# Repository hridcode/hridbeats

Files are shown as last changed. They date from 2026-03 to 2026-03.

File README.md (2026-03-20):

# hridBeats
hridBeats is an open-source sample chopper, synth, and MIDI controller based off the Raspberry Pi Pico. 

# Features

- 12 touchpads
- 8 potentiometers
- rotary encoder with a pushbutton
- joystick for mouse control
- TFT LCD 2.0" ST7789 display
- PCM5102A I2S DAC board for audio output
- SD card slot for loading songs/samples
- MIDI through USB
- Mini synth engine

# Pictures

|Schematic|PCB|Case|
|---|---|---|
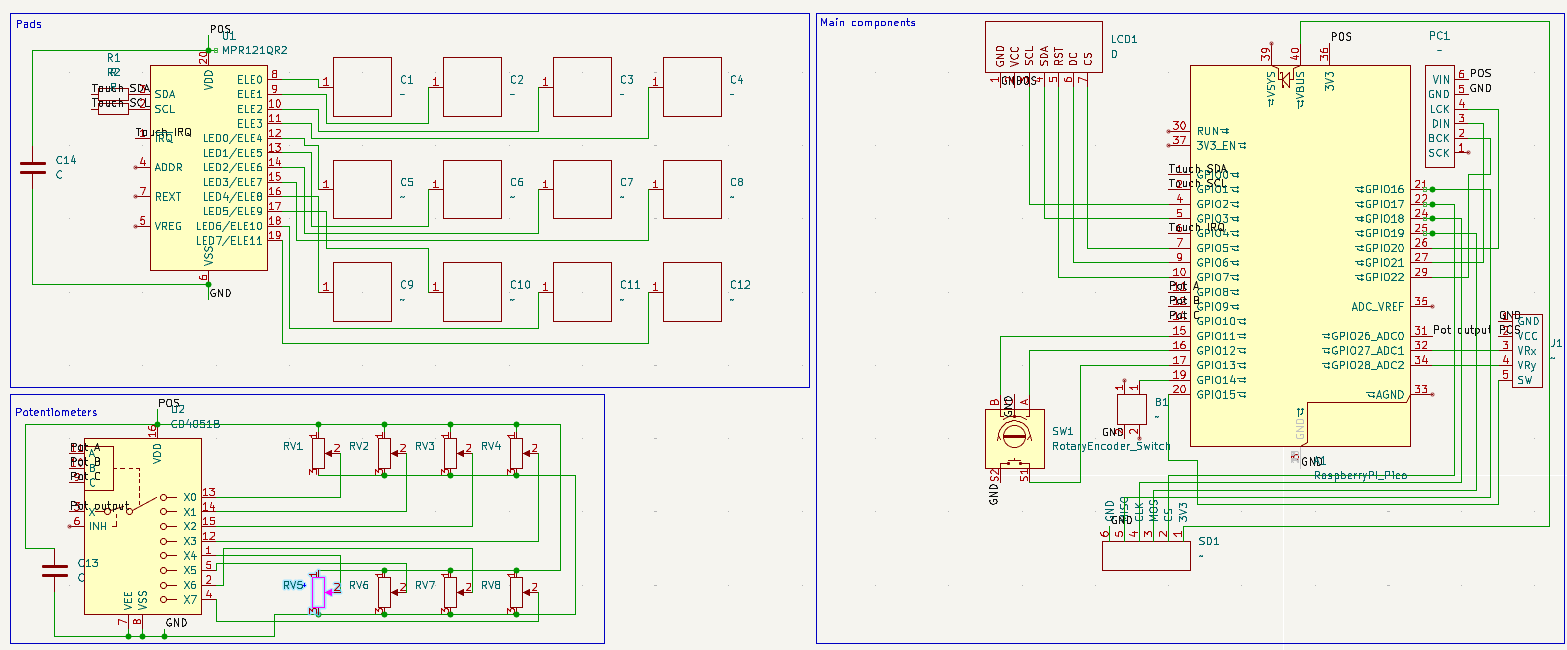
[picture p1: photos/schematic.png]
Image of schematic
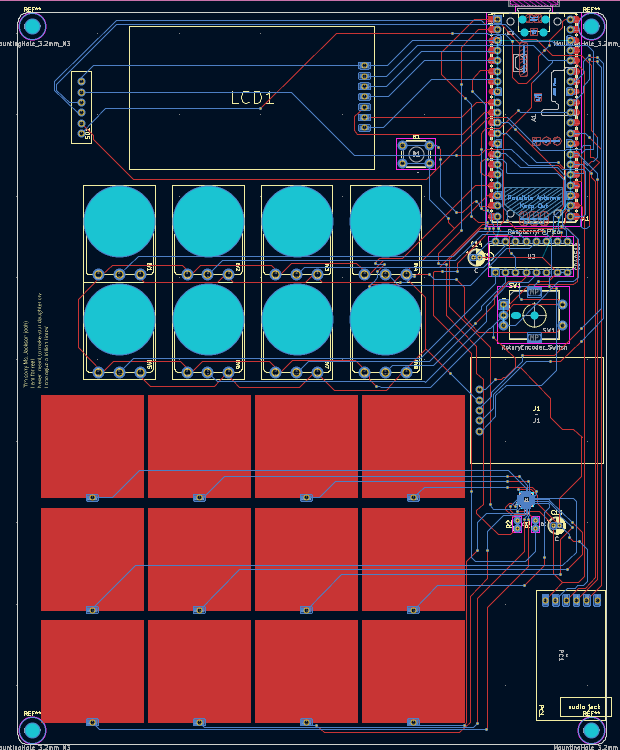
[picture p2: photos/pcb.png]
Image of PCB
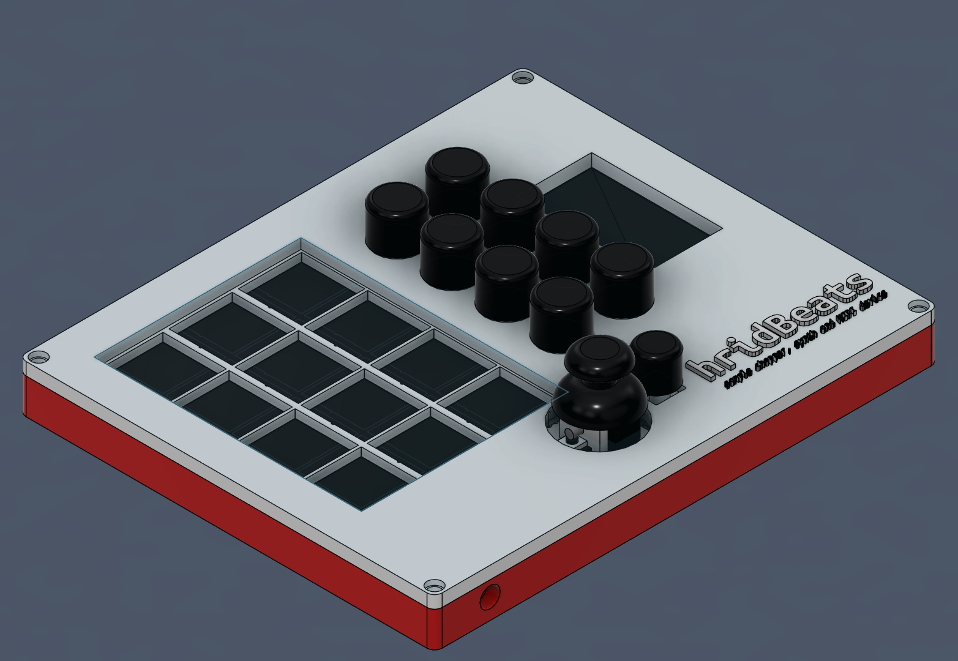
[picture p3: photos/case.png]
Image of case
||||

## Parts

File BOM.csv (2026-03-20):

Item | Count | Price | Link
MPR121QR2 | 1 | 1 | https://www.aliexpress.us/item/3256806758406295.html?curPageLogUid=pTX3BiAzX3DO
PCM5102A I2S DAC board | 1 | 2.28 | https://www.aliexpress.us/item/3256808911242738.html?curPageLogUid=evOArS7vqeJX
2.0" TFT LCD ST7789 display | 1 | 3.76 | https://www.aliexpress.us/item/3256808604687621.html?curPageLogUid=fdDO3YdVQrhY
WH148 potentiometer | 10 | 4.02 | https://www.aliexpress.us/item/3256808118980669.html?curPageLogUid=byGJ2gZeQC04
EC11 rotary encoder (w/ push button) | 1 | 0.65 | https://www.aliexpress.us/item/2261799870168498.html?curPageLogUid=hjV5hj8fpuzV
KY-023 joystick module | 1 | 1.25 | https://www.aliexpress.us/item/3256807353588090.html?curPageLogUid=3KMLlz3LYJ8L
Raspberry Pi Pico | 1 | 3.95 | https://www.pishop.us/product/raspberry-pi-pico/?src=raspberrypi
M3 heatset inserts 3x5x4 | 8 | 0.32 | https://www.aliexpress.us/item/3256806651793931.html?curPageLogUid=qsMqfJvH4nXo
M3x8 screws | 8 | 0.32 | https://www.aliexpress.us/item/3256804883804669.html?curPageLogUid=Ex37TlD5EHOc
3D printed parts (12 pads, 9 knobs, top & bottom case) | 23 | - | -
PCB | 1 | 2.76 | https://cart.jlcpcb.com/quote?stencilLayer=2&stencilWidth=144&stencilLength=169&stencilCounts=5&plateType=1
Total | - | 20.31

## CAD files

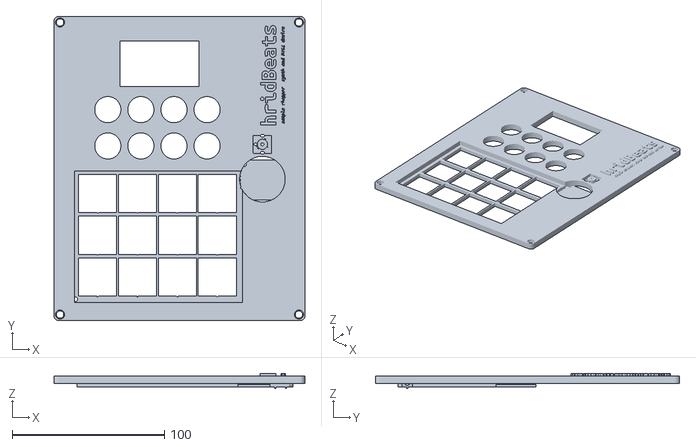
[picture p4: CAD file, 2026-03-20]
production/cad/TopCase.stl
165.0 x 200.0 x 9.77

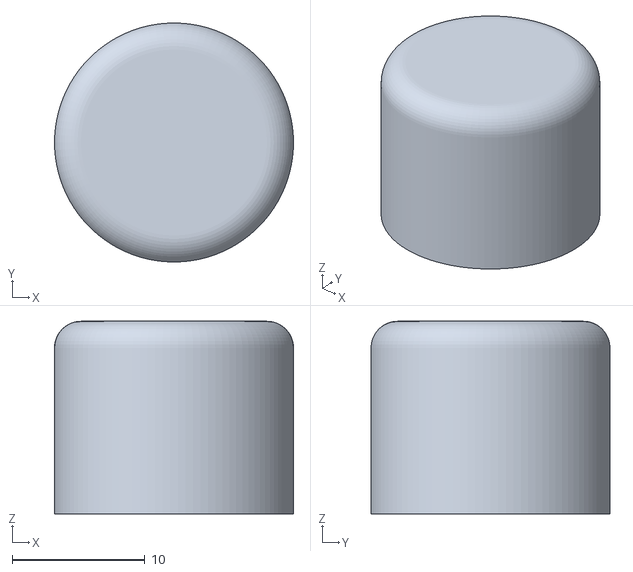
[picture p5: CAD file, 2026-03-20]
production/cad/Knob.stl
18.0 x 18.0 x 14.5

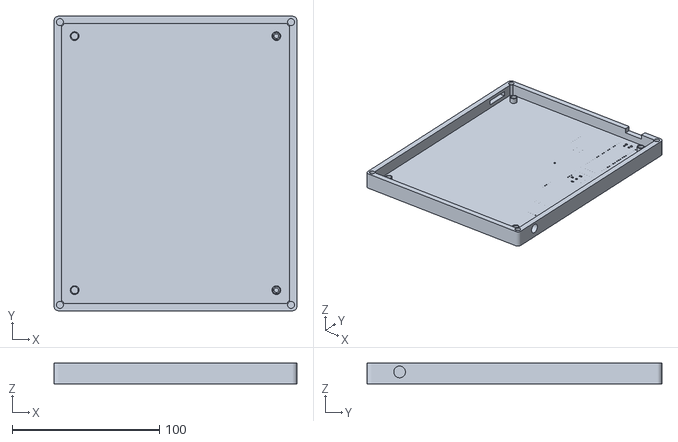
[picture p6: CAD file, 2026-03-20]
production/cad/BottomCase.stl
165.0 x 200.0 x 14.0

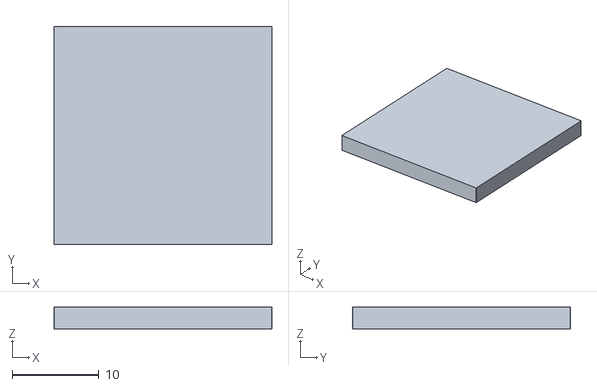
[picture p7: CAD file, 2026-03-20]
production/cad/Pad.stl
25.1 x 25.1 x 2.50

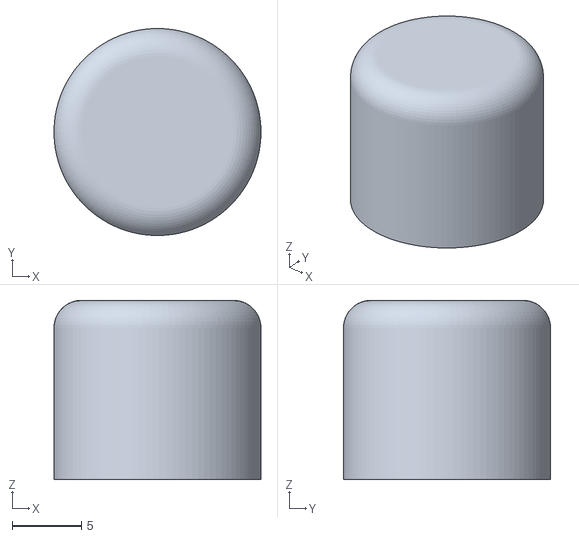
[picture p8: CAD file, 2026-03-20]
production/cad/Knob_RotaryEncoder.stl
15.0 x 15.0 x 13.0

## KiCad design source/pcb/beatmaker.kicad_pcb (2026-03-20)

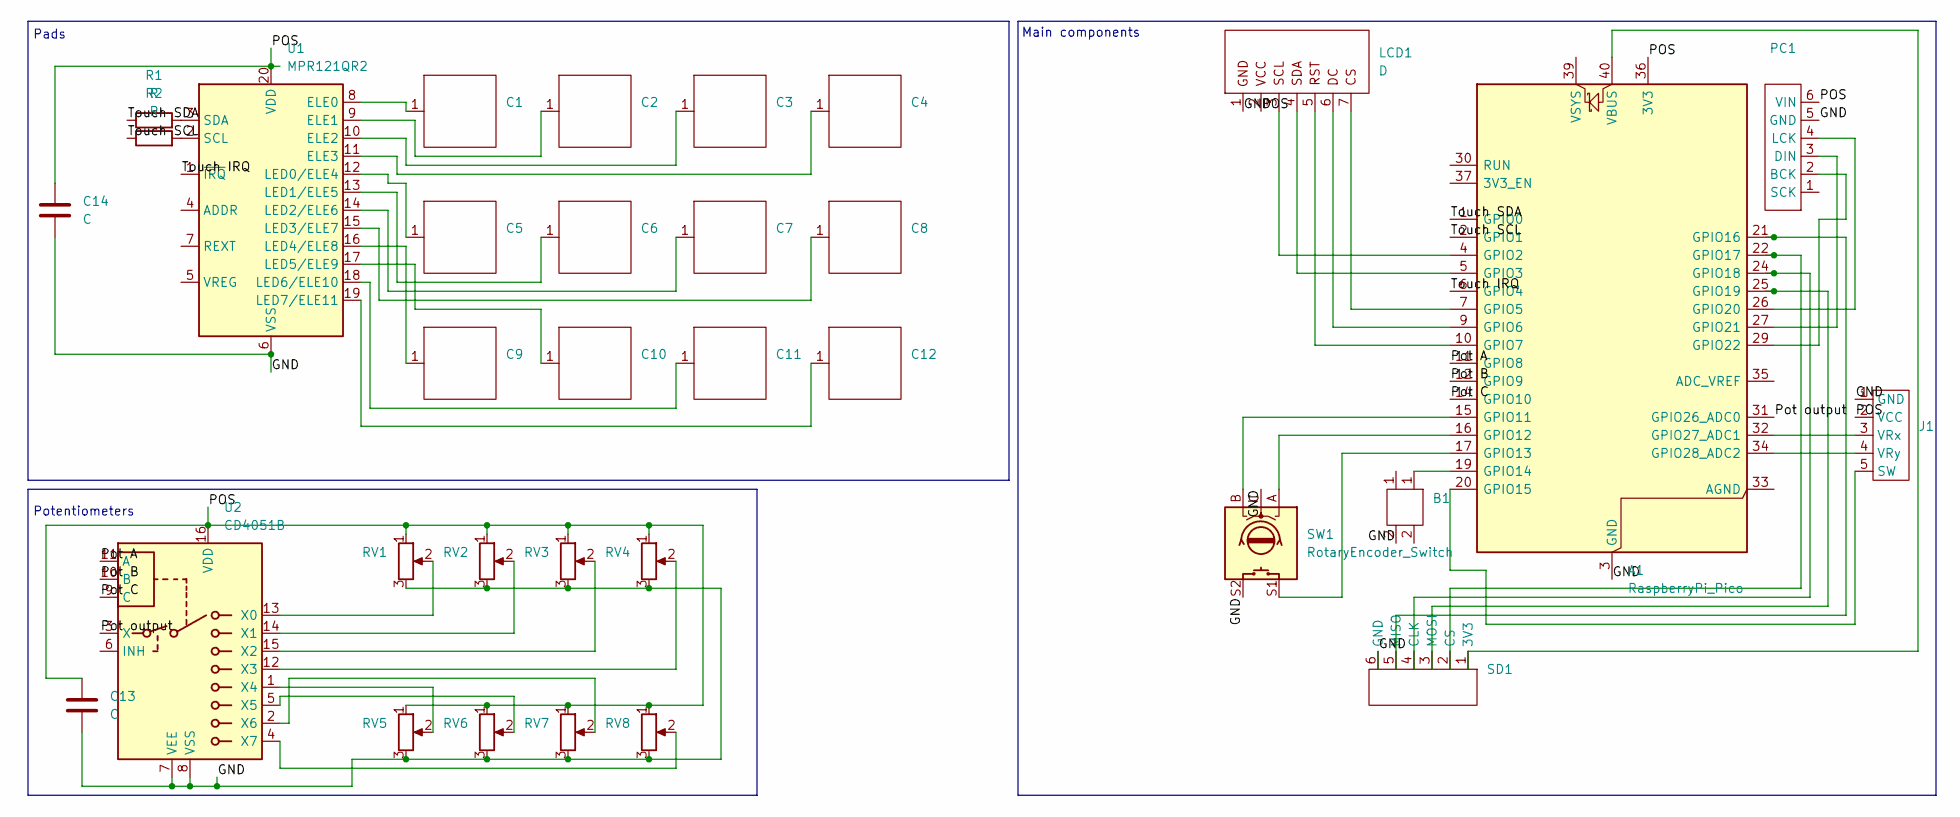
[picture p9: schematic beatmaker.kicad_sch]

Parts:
A1: RaspberryPi_Pico; RaspberryPi_Pico_Common_Unspecified
B1: SW_PUSH_6mm
C1, C2, C3, C4, C5, C6, C7, C8, C9, C10, C11, C12: copper_pad_25mm
C13, C14: C; CP_Radial_D4.0mm_P1.50mm
J1: ky-023-joystick
LCD1: D; ST7789
PC1: PCM5201-Board
R1, R2: R; R_Axial_DIN0204_L3.6mm_D1.6mm_P1.90mm_Vertical
RV1, RV2, RV3, RV4, RV5, RV6, RV7, RV8: R_Potentiometer; potentiometer
SD1: sd_card_module
SW1: RotaryEncoder_Switch; RotaryEncoder_Alps_EC11E-Switch_Vertical_H20mm_MountingHoles
U1: MPR121QR2; UQFN-20_3x3mm_P0.4mm
U2: CD4051B; DIP-16_W7.62mm

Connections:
/GND: A1.3 (GND), A1.8 (GND), A1.13 (GND), A1.18 (GND), A1.23 (GND), A1.28 (GND), A1.38 (GND), B1.2, C13.2, C14.2, J1.1 (GND), LCD1.1, PC1.5 (GND), RV1.3, RV2.3, RV3.3, RV4.3, RV5.3, RV6.3, RV7.3, RV8.3, SD1.6 (GND), SW1.C, SW1.S2, U1.6 (VSS), U2.7 (VEE), U2.8 (VSS)
/POS: A1.36 (3V3), C13.1, C14.1, J1.2 (VCC), LCD1.2, PC1.6 (VIN), RV1.1, RV2.1, RV3.1, RV4.1, RV5.1, RV6.1, RV7.1, RV8.1, U1.20 (VDD), U2.16 (VDD)
/Pot A: A1.11 (GPIO8), U2.11 (A)
/Pot B: A1.12 (GPIO9), U2.10 (B)
/Pot C: A1.14 (GPIO10), U2.9 (C)
/Pot output: A1.31 (GPIO26_ADC0), U2.3 (X)
/Touch IRQ: A1.6 (GPIO4), U1.1 (~IRQ)
/Touch SCL: A1.2 (GPIO1), R2.1
/Touch SDA: A1.1 (GPIO0), R1.1
unnamed: A1.4 (GPIO2), LCD1.3
unnamed: A1.5 (GPIO3), LCD1.4
unnamed: A1.7 (GPIO5), LCD1.7
unnamed: A1.9 (GPIO6), LCD1.6
unnamed: A1.10 (GPIO7), LCD1.5
unnamed: A1.15 (GPIO11), SW1.B
unnamed: A1.16 (GPIO12), SW1.A
unnamed: A1.17 (GPIO13), SW1.S1
unnamed: A1.19 (GPIO14), B1.1
unnamed: A1.20 (GPIO15), J1.5 (SW)
unnamed: A1.21 (GPIO16), SD1.5 (MISO)
unnamed: A1.22 (GPIO17), SD1.2 (CS)
unnamed: A1.24 (GPIO18), SD1.4 (CLK)
unnamed: A1.25 (GPIO19), SD1.3 (MOSI)
unnamed: A1.26 (GPIO20), PC1.4 (LCK)
unnamed: A1.27 (GPIO21), PC1.3 (DIN)
unnamed: A1.29 (GPIO22), PC1.2 (BCK)
unnamed: A1.32 (GPIO27_ADC1), J1.3 (VRx)
unnamed: A1.34 (GPIO28_ADC2), J1.4 (VRy)
unnamed: A1.40 (VBUS), SD1.1 (3V3)
unnamed: C1.1, U1.8 (ELE0)
unnamed: C2.1, U1.9 (ELE1)
unnamed: C3.1, U1.10 (ELE2)
unnamed: C4.1, U1.11 (ELE3)
unnamed: C5.1, U1.12 (LED0/ELE4)
unnamed: C6.1, U1.13 (LED1/ELE5)
unnamed: C7.1, U1.14 (LED2/ELE6)
unnamed: C8.1, U1.15 (LED3/ELE7)
unnamed: C9.1, U1.16 (LED4/ELE8)
unnamed: C10.1, U1.17 (LED5/ELE9)
unnamed: C11.1, U1.18 (LED6/ELE10)
unnamed: C12.1, U1.19 (LED7/ELE11)
unnamed: R2.2, U1.2 (SCL)
unnamed: R1.2, U1.3 (SDA)
unnamed: RV1.2, U2.13 (X0)
unnamed: RV2.2, U2.14 (X1)
unnamed: RV3.2, U2.15 (X2)
unnamed: RV4.2, U2.12 (X3)
unnamed: RV5.2, U2.1 (X4)
unnamed: RV6.2, U2.5 (X5)
unnamed: RV7.2, U2.2 (X6)
unnamed: RV8.2, U2.4 (X7)

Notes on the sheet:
Pads
Potentiometers
Main components

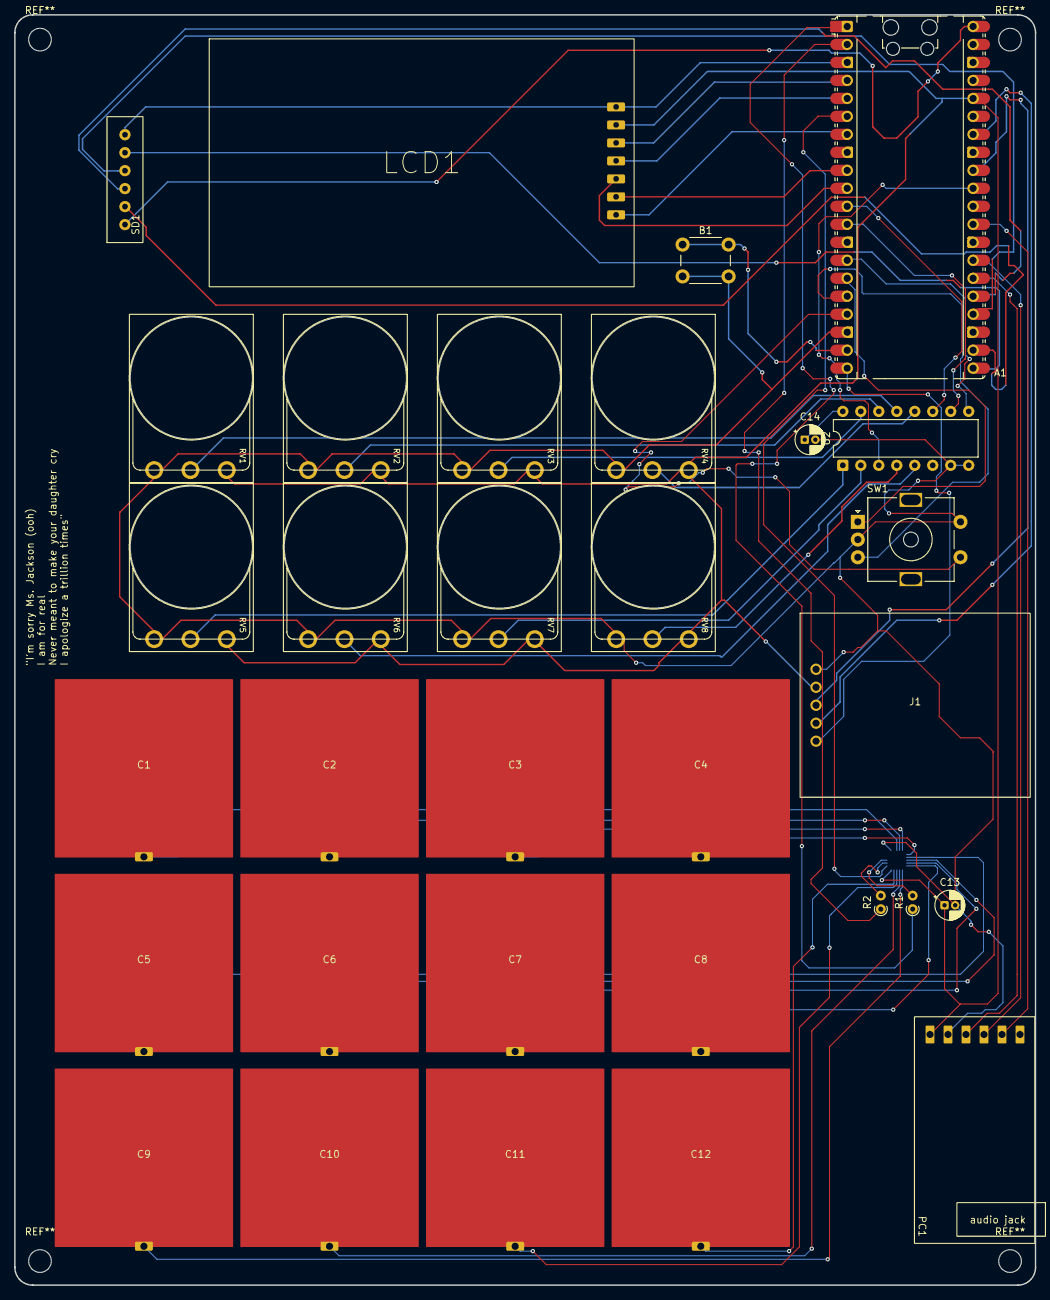
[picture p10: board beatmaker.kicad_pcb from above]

Board: 2 copper layers, 144.2 x 179.4 mm, 33 parts (1 on the bottom side), 51 nets.

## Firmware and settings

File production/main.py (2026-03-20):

from machine import Pin, PWM, SPI, ADC
from sdcard import SDCard
import spleen8, spleen16
import layout
import time, os
import framebuf
from st7789py import color565, WHITE, YELLOW

joystick_x, joystick_y = ADC(Pin(27)), ADC(Pin(28))
joystick_sw = Pin(15, pull=Pin.PULL_UP)

pot = ADC(Pin(26))
pot_left, pot_right = Pin(8, pull=Pin.PULL_UP), Pin(9, pull=Pin.PULL_UP)

rotary_l, rotary_r = Pin(11), Pin(12)
rotary_push = Pin(13, pull=Pin.PULL_UP)

int_button = Pin(14, pull=Pin.PULL_UP)

sd_spi = SPI(0, sck=Pin(18, Pin.OUT), mosi=Pin(19, Pin.OUT), miso=Pin(16))
sd_cs = Pin(17, Pin.OUT)

sd = SDCard(sd_spi, sd_cs)

vfs = os.VfsFat(sd) # type: ignore

os.mount(vfs, "/sd")
print("Filesystem check")
print(os.listdir("/sd"))

BG_COLOR = color565(75, 86, 130)
STATUS_BAR_GRAY = color565(80, 80, 80)
BUTTON_GRAY = color565(170, 170, 170)

screen = layout.Screen(BG_COLOR)

home_root = layout.Container(0, 0, 320, 240)
status = layout.StatusBar(0, 32, "Hello world!", STATUS_BAR_GRAY, WHITE)
home_root.add(status)

new_project_button = layout.Button(160, 100, 210, 50, "New Project", BUTTON_GRAY, WHITE, STATUS_BAR_GRAY)
open_project_button = layout.Button(160, 172, 210, 50, "Open Project", BUTTON_GRAY, WHITE, STATUS_BAR_GRAY)
home_root.add(new_project_button, open_project_button)

screen.set_root(home_root)

screen.render(fill=True, layout=True)

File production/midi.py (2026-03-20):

# MicroPython USB MIDI module
# MIT license; Copyright (c) 2023 Paul Hamshere, 2023-2024 Angus Gratton
from micropython import const, schedule
import struct

from .core import Interface, Buffer

_EP_IN_FLAG = const(1 << 7)

_INTERFACE_CLASS_AUDIO = const(0x01)
_INTERFACE_SUBCLASS_AUDIO_CONTROL = const(0x01)
_INTERFACE_SUBCLASS_AUDIO_MIDISTREAMING = const(0x03)

# Audio subclass extends the standard endpoint descriptor
# with two extra bytes
_STD_DESC_AUDIO_ENDPOINT_LEN = const(9)
_CLASS_DESC_ENDPOINT_LEN = const(5)

_STD_DESC_ENDPOINT_TYPE = const(0x5)

_JACK_TYPE_EMBEDDED = const(0x01)
_JACK_TYPE_EXTERNAL = const(0x02)

_JACK_IN_DESC_LEN = const(6)
_JACK_OUT_DESC_LEN = const(9)

# MIDI Status bytes. For Channel messages these are only the upper 4 bits, ORed with the channel number.
# As per https://www.midi.org/specifications-old/item/table-1-summary-of-midi-message
_MIDI_NOTE_OFF = const(0x80)
_MIDI_NOTE_ON = const(0x90)
_MIDI_POLY_KEYPRESS = const(0xA0)
_MIDI_CONTROL_CHANGE = const(0xB0)

# USB-MIDI CINs (Code Index Numbers), as per USB MIDI Table 4-1
_CIN_SYS_COMMON_2BYTE = const(0x2)
_CIN_SYS_COMMON_3BYTE = const(0x3)
_CIN_SYSEX_START = const(0x4)
_CIN_SYSEX_END_1BYTE = const(0x5)
_CIN_SYSEX_END_2BYTE = const(0x6)
_CIN_SYSEX_END_3BYTE = const(0x7)
_CIN_NOTE_OFF = const(0x8)
_CIN_NOTE_ON = const(0x9)
_CIN_POLY_KEYPRESS = const(0xA)
_CIN_CONTROL_CHANGE = const(0xB)
_CIN_PROGRAM_CHANGE = const(0xC)
_CIN_CHANNEL_PRESSURE = const(0xD)
_CIN_PITCH_BEND = const(0xE)
_CIN_SINGLE_BYTE = const(0xF)  # Not currently supported

# Jack IDs for a simple bidrectional MIDI device(!)
_EMB_IN_JACK_ID = const(1)
_EXT_IN_JACK_ID = const(2)
_EMB_OUT_JACK_ID = const(3)
_EXT_OUT_JACK_ID = const(4)

# Data flows, as modelled by USB-MIDI and this hypothetical interface, are as follows:
# Device RX = USB OUT EP => _EMB_IN_JACK => _EMB_OUT_JACK
# Device TX = _EXT_IN_JACK => _EMB_OUT_JACK => USB IN EP


class MIDIInterface(Interface):
    # Base class to implement a USB MIDI device in Python.
    #
    # To be compliant this also registers a dummy USB Audio interface, but that
    # interface isn't otherwise used.

    def __init__(self, rxlen=16, txlen=16):
        # Arguments are size of transmit and receive buffers in bytes.

        super().__init__()
        self.ep_out = None  # Set during enumeration. RX direction (host to device)
        self.ep_in = None  # TX direction (device to host)
        self._rx = Buffer(rxlen)
        self._tx = Buffer(txlen)

    # Callbacks for handling received MIDI messages.
    #
    # Subclasses can choose between overriding on_midi_event
    # and handling all MIDI events manually, or overriding the
    # functions for note on/off and control change, only.

    def on_midi_event(self, cin, midi0, midi1, midi2):
        ch = midi0 & 0x0F
        if cin == _CIN_NOTE_ON:
            self.on_note_on(ch, midi1, midi2)
        elif cin == _CIN_NOTE_OFF:
            self.on_note_off(ch, midi1, midi2)
        elif cin == _CIN_CONTROL_CHANGE:
            self.on_control_change(ch, midi1, midi2)

    def on_note_on(self, channel, pitch, vel):
        pass  # Override to handle Note On messages

    def on_note_off(self, channel, pitch, vel):
        pass  # Override to handle Note On messages

    def on_control_change(self, channel, controller, value):
        pass  # Override to handle Control Change messages

    # Helper functions for sending common MIDI messages

    def note_on(self, channel, pitch, vel=0x40):
        self.send_event(_CIN_NOTE_ON, _MIDI_NOTE_ON | channel, pitch, vel)

    def note_off(self, channel, pitch, vel=0x40):
        self.send_event(_CIN_NOTE_OFF, _MIDI_NOTE_OFF | channel, pitch, vel)

    def control_change(self, channel, controller, value):
        self.send_event(_CIN_CONTROL_CHANGE, _MIDI_CONTROL_CHANGE | channel, controller, value)

    def send_event(self, cin, midi0, midi1=0, midi2=0):
        # Queue a MIDI Event Packet to send to the host.
        #
        # CIN = USB-MIDI Code Index Number, see USB MIDI 1.0 section 4 "USB-MIDI Event Packets"
        #
        # Remaining arguments are 0-3 MIDI data bytes.
        #
        # Note this function returns when the MIDI Event Packet has been queued,
        # not when it's been received by the host.
        #
        # Returns False if the TX buffer is full and the MIDI Event could not be queued.
        w = self._tx.pend_write()
        if len(w) < 4:
            return False  # TX buffer is full. TODO: block here?
        w[0] = cin  # leave cable number as 0?
        w[1] = midi0
        w[2] = midi1
        w[3] = midi2
        self._tx.finish_write(4)
        self._tx_xfer()
        return True

    def _tx_xfer(self):
        # Keep an active IN transfer to send data to the host, whenever
        # there is data to send.
        if self.is_open() and not self.xfer_pending(self.ep_in) and self._tx.readable():
            self.submit_xfer(self.ep_in, self._tx.pend_read(), self._tx_cb)

    def _tx_cb(self, ep, res, num_bytes):
        if res == 0:
            self._tx.finish_read(num_bytes)
        self._tx_xfer()

    def _rx_xfer(self):
        # Keep an active OUT transfer to receive MIDI events from the host
        if self.is_open() and not self.xfer_pending(self.ep_out) and self._rx.writable():
            self.submit_xfer(self.ep_out, self._rx.pend_write(), self._rx_cb)

    def _rx_cb(self, ep, res, num_bytes):
        if res == 0:
            self._rx.finish_write(num_bytes)
            schedule(self._on_rx, None)
        self._rx_xfer()

    def on_open(self):
        super().on_open()
        # kick off any transfers that may have queued while the device was not open
        self._tx_xfer()
        self._rx_xfer()

    def _on_rx(self, _):
        # Receive MIDI events. Called via micropython.schedule, outside of the USB callback function.
        m = self._rx.pend_read()
        i = 0
        while i <= len(m) - 4:
            cin = m[i] & 0x0F
            self.on_midi_event(cin, m[i + 1], m[i + 2], m[i + 3])
            i += 4
        self._rx.finish_read(i)

    def desc_cfg(self, desc, itf_num, ep_num, strs):
        # Start by registering a USB Audio Control interface, that is required to point to the
        # actual MIDI interface
        desc.interface(itf_num, 0, _INTERFACE_CLASS_AUDIO, _INTERFACE_SUBCLASS_AUDIO_CONTROL)

        # Append the class-specific AudioControl interface descriptor
        desc.pack(
            "<BBBHHBB",
            9,  # bLength
            0x24,  # bDescriptorType CS_INTERFACE
            0x01,  # bDescriptorSubtype MS_HEADER
            0x0100,  # BcdADC
            0x0009,  # wTotalLength
            0x01,  # bInCollection,
            itf_num + 1,  # baInterfaceNr - points to the MIDI Streaming interface
        )

        # Next add the MIDI Streaming interface descriptor
        desc.interface(
            itf_num + 1, 2, _INTERFACE_CLASS_AUDIO, _INTERFACE_SUBCLASS_AUDIO_MIDISTREAMING
        )
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

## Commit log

2026-03-20 Added source + production files
    [BottomCase.stl, Knob.stl, Knob_RotaryEncoder.stl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]
2026-03-20 Added BOM.csv
    [BOM.csv]
